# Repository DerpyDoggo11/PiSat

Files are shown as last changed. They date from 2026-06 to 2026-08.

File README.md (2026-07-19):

# PiSat
A GPS Microcontroller for RTK GPS applications

## 3D Preview
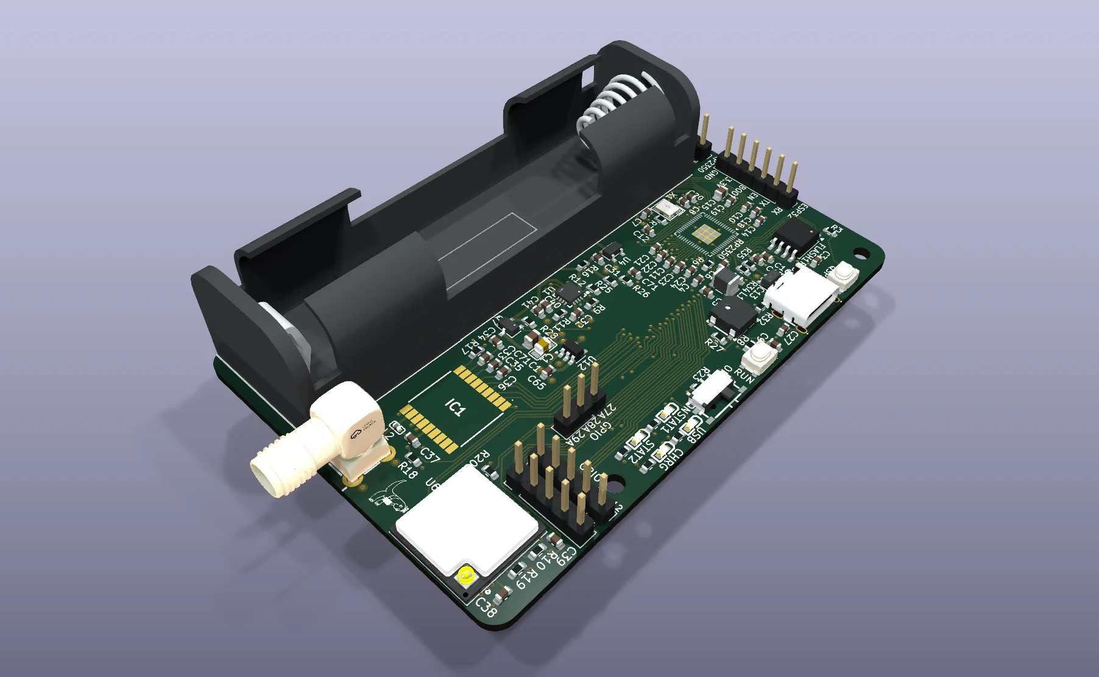
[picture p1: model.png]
3D PCB


## Wiring
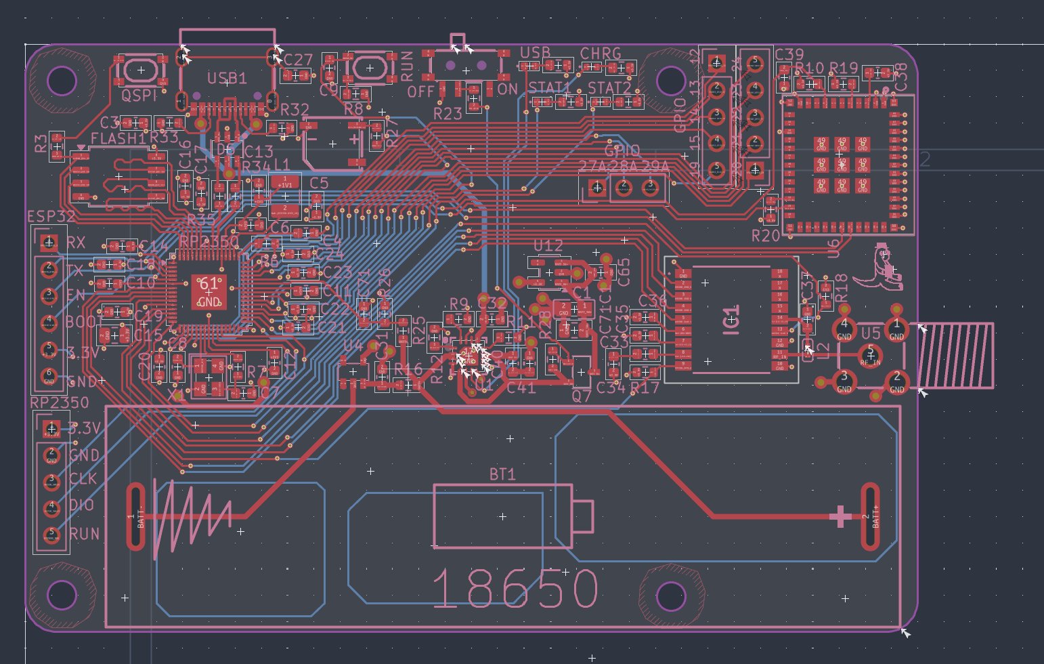
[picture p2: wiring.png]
PCB


## Schematic
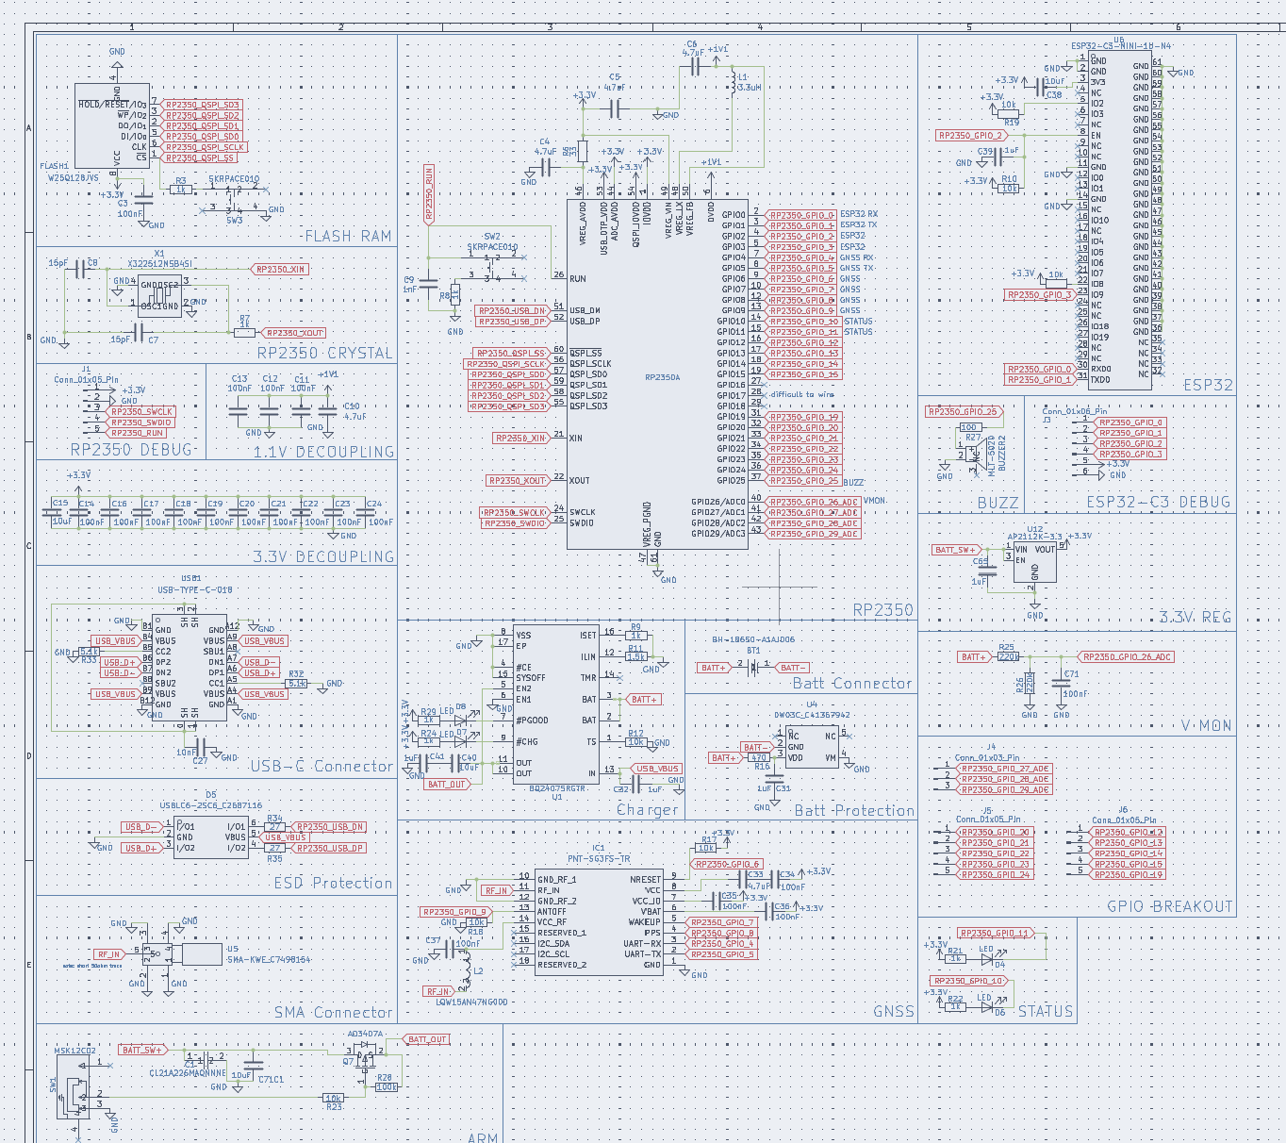
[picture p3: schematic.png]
Schematic


### Download the ./latestProduction folder to begin fabricating through JLCPCB. 

## Introduction
PiSat is a complete microcontroller with an embbedded GPS chip all in the footprint of a Raspbbery Pi. It uses an RP2350 for parallel computing + an esp32 for wifi connectivity. In addition, it uses the PNT-SG3FS-TR GPS chip with an SMA connector to attach an external GPS antenna. It also can run completely on battery power for an estimated 12 hours (based on the suggested battery) at full load.

The main use case for this is in the Real Time Kinematic (RTK) GPS system, which requires two GPS recievers: one at a known location and one at the location being tracked. By calculating the error that both recievers share with other satilletes, this method can track an object down to just a few centimeters. The main drawback to RTK GPS systems is that they usually require expensive mcu for the calculations + external GPS modules which can increase the cost substantially. A fully embbedded approach makes the price much more approachable to hobbists.

Note: this is licensed under the GPL/GNU license which means editing it is fine, just make sure to keep it open source.

## Bill of Materials 

### (Minimum build for RTK GPS system: 2 PiSats)

| Quantity | Components |  Price | Link |
|--- |---|---| -----|
| 2  | 18650 Batteries | ~$20 (with shipping) | [here](https://liionwholesale.com/products/molicel-npe-inr-18650-m35a-10a-3500mah-flat-top-18650-battery-authorized-distributor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)
| 2 | GPS Antenna | $7 (Flexible Antenna) or $10 (Straight Antenna) | [here](https://www.aliexpress.us/item/3256804609969855.html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) or [here](https://www.aliexpress.us/item/3256809038076860.html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)
| 2 | 2.4G Wifi Antenna | $3.55 | [here](https://www.aliexpress.us/item/3256802833801038.html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)
| 2  | PiSat PCBs | ~$100 (with shipping, cost can vary widely however) | Download repo, extract fabrication files from ./latestProduction, and fabricate through JLCPCB (complete instructions for this may come soon)

Total cost: **$130.55**

Cost per unit: **$65.28**

----

## Tools:
- Soldering iron + solder

## Assembly:
1. (If using vertical mount case) Screw into 3 of the mounting holes on the board, only screw into the 1 mounting hole below the battery if completely necessary
2. Solder on the battery connector
3. Screw in the wifi antenna onto the esp32
4. Screw in the GPS antenna onto the SMA connector
5. Insert battery into battery connector and turn on

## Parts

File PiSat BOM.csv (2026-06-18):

Quantity | Component | Price | Link
80 | Brushed DC Motor | $54.88 | https://www.aliexpress.us/item/3256810271706869.html
20 | 1s 450mAh BT2.0 Battery | $61.82 | https://www.aliexpress.us/item/3256810349502140.html?curPageLogUid=6cUgOJiOwfNW
2 | 1s BT2.0 Charger | $36.36 | https://www.aliexpress.us/item/3256811772590472.html?curPageLogUid=pie8lE5eVKgd
20 | BMP581 (hand solder) | $74.76 | https://www.lcsc.com/product-detail/C5362283.html?s_z=s_p_BMP581
20 | LSM6DSRTR (hand solder) | $60.13 | https://www.lcsc.com/product-detail/C784817.html?s_z=s_q_LSM6DSR
20 | BT2.0 Battery Connector | $61 | https://www.aliexpress.us/item/3256809239979303.html?curPageLogUid=TSeGJiqu7rZ1 | Note: select "1S Whoop"
20 | 2.4G Wifi Antenna | $14.08 | https://www.aliexpress.us/item/3256802833801038.html?curPageLogUid=rLnZuf4b98Bi
20 | Custom PCB | $200 | Fab files available on github
Total: | $562.95
Unit Cost: | $25.40

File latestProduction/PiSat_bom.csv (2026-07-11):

Designator | Footprint | Quantity | Value | LCSC Part #
BT1 | BAT-TH_BH-18650-A1AJ006 | 1 | BH-18650-A1AJ006 | C5290175
BUZZER2 | BUZ-SMD_L5.0-W5.5-P4.60 | 1 | MLT-5020 | C94598
C1 | C0805 | 1 | CL21A226MAQNNNE | C45783
C10, C33, C4, C5, C6 | 0603 | 5 | 4.7uF
C11, C12, C13, C14, C16, C17, C18, C19, C20, C21, C22, C23, C24, C3, C34, C35, C36, C37, C71 | 0603 | 19 | 100nF
C15, C71C1 | 0805 | 2 | 10uF
C27 | 0603 | 1 | 10nF
C31, C32, C39, C41, C65 | 0603 | 5 | 1uF
C38, C40 | 0603 | 2 | 10uF
C7, C8 | 0603 | 2 | 15pF
C9 | 0603 | 1 | 1nF
D5 | SOT-23-6_L2.9-W1.6-P0.95-LS2.8-BL | 1 | USBLC6-2SC6_C2687116 | C2687116
FLASH1 | SOIC-8_5.3x5.3mm_P1.27mm | 1 | W25Q128JVS
IC1 | PNTSG3FSTR | 1 | PNT-SG3FS-TR
J1, J5, J6 | PinHeader_1x05_P2.54mm_Vertical | 3 | Conn_01x05_Pin
J3 | PinHeader_1x06_P2.54mm_Vertical | 1 | Conn_01x06_Pin
J4 | PinHeader_1x03_P2.54mm_Vertical | 1 | Conn_01x03_Pin
L1 | 1210 | 1 | 3.3uH
L2 | L0402 | 1 | LQW15AN47NG00D | C22334
LED4, LED5, LED6, LED7 | LED-SMD_L1.6-W0.8-R-RD | 4 | KT-0603R | C2286
Q7 | SOT-23-3_L2.9-W1.6-P1.90-LS2.8-BR | 1 | AO3407A | C15155
R10, R12, R17, R18, R19, R20, R23 | 0603 | 7 | 10k
R11 | 0603 | 1 | 1.5k
R16 | 0603 | 1 | 470
R21, R22, R24, R29, R3, R7, R8, R9 | 0603 | 8 | 1k
R25, R26 | 0603 | 2 | 220k
R27 | 0603 | 1 | 100
R28 | 0603 | 1 | 100k
R32, R33 | 0603 | 2 | 5.1k
R34, R35 | 0603 | 2 | 27
R6 | 0603 | 1 | 33
RP2350 | QFN-60-1EP_7x7mm_P0.4mm_EP3.4x3.4mm | 1 | RP2350A
SW1 | SW-TH_MSK12C02 | 1 | MSK12C02 | C431540
SW2, SW3 | KEY-SMD_4P-L4.2-W3.2-P2.20-LS4.6 | 2 | SKRPACE010 | C139797
U1 | QFN-16_L3.0-W3.0-P0.50-TL-EP1.7 | 1 | BQ24075RGTR | C15464
U12 | SOT-23-5 | 1 | AP2112K-3.3
U4 | SOT-23-5_L2.9-W1.6-P0.95-LS2.9-BL | 1 | DW03C_C41367942 | C41367942
U5 | SMA-TH_SMA-KWE_C7498154 | 1 | SMA-KWE_C7498154 | C7498154
U6 | WIFIM-SMD_61P-L13.2-W12.5-P0.80 | 1 | ESP32-C3-MINI-1U-N4 | C2911374
USB1 | USB-C_SMD-TYPE-C-31-M-12 | 1 | USB-TYPE-C-018 | C2927038
X1 | CRYSTAL-SMD_4P-L3.2-W2.5-BL | 1 | X322512MSB4SI | C9002

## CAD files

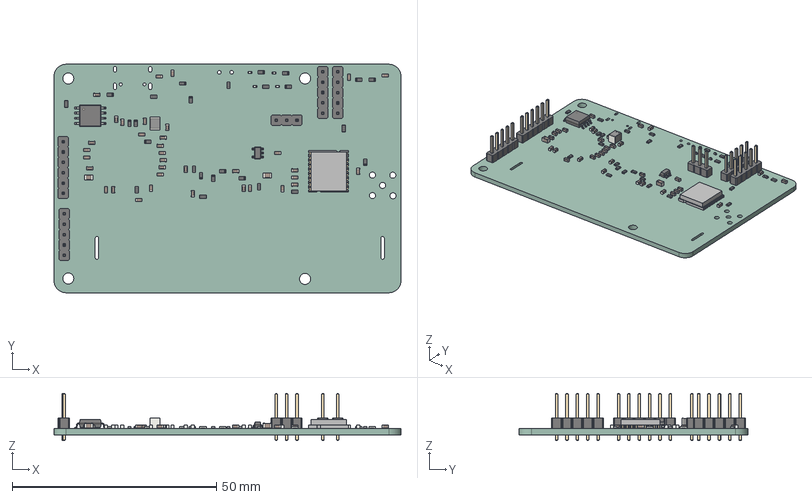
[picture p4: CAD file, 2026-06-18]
latestProduction/PiSat.step
85.0 x 56.0 x 11.5 mm
C_0603_1608Metric x 35
R_0603_1608Metric x 26
PinHeader_1x06_P2.54mm_Vertical
C_0805_2012Metric x 2
LED_0402_1005Metric x 4
L_1210_3225Metric
SOT-23-5
SOIC-8_5.3x5.3mm_P1.27mm
PinHeader_1x03_P2.54mm_Vertical
PinHeader_1x05_P2.54mm_Vertical x 3
PNT-SG3FS-TR
PiSat_PCB

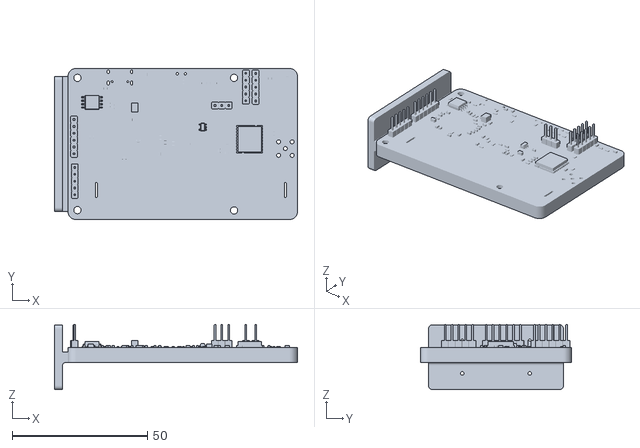
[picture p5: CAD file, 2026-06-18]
PiSat Vertical Mount Case.stl
90.0 x 56.0 x 24.1

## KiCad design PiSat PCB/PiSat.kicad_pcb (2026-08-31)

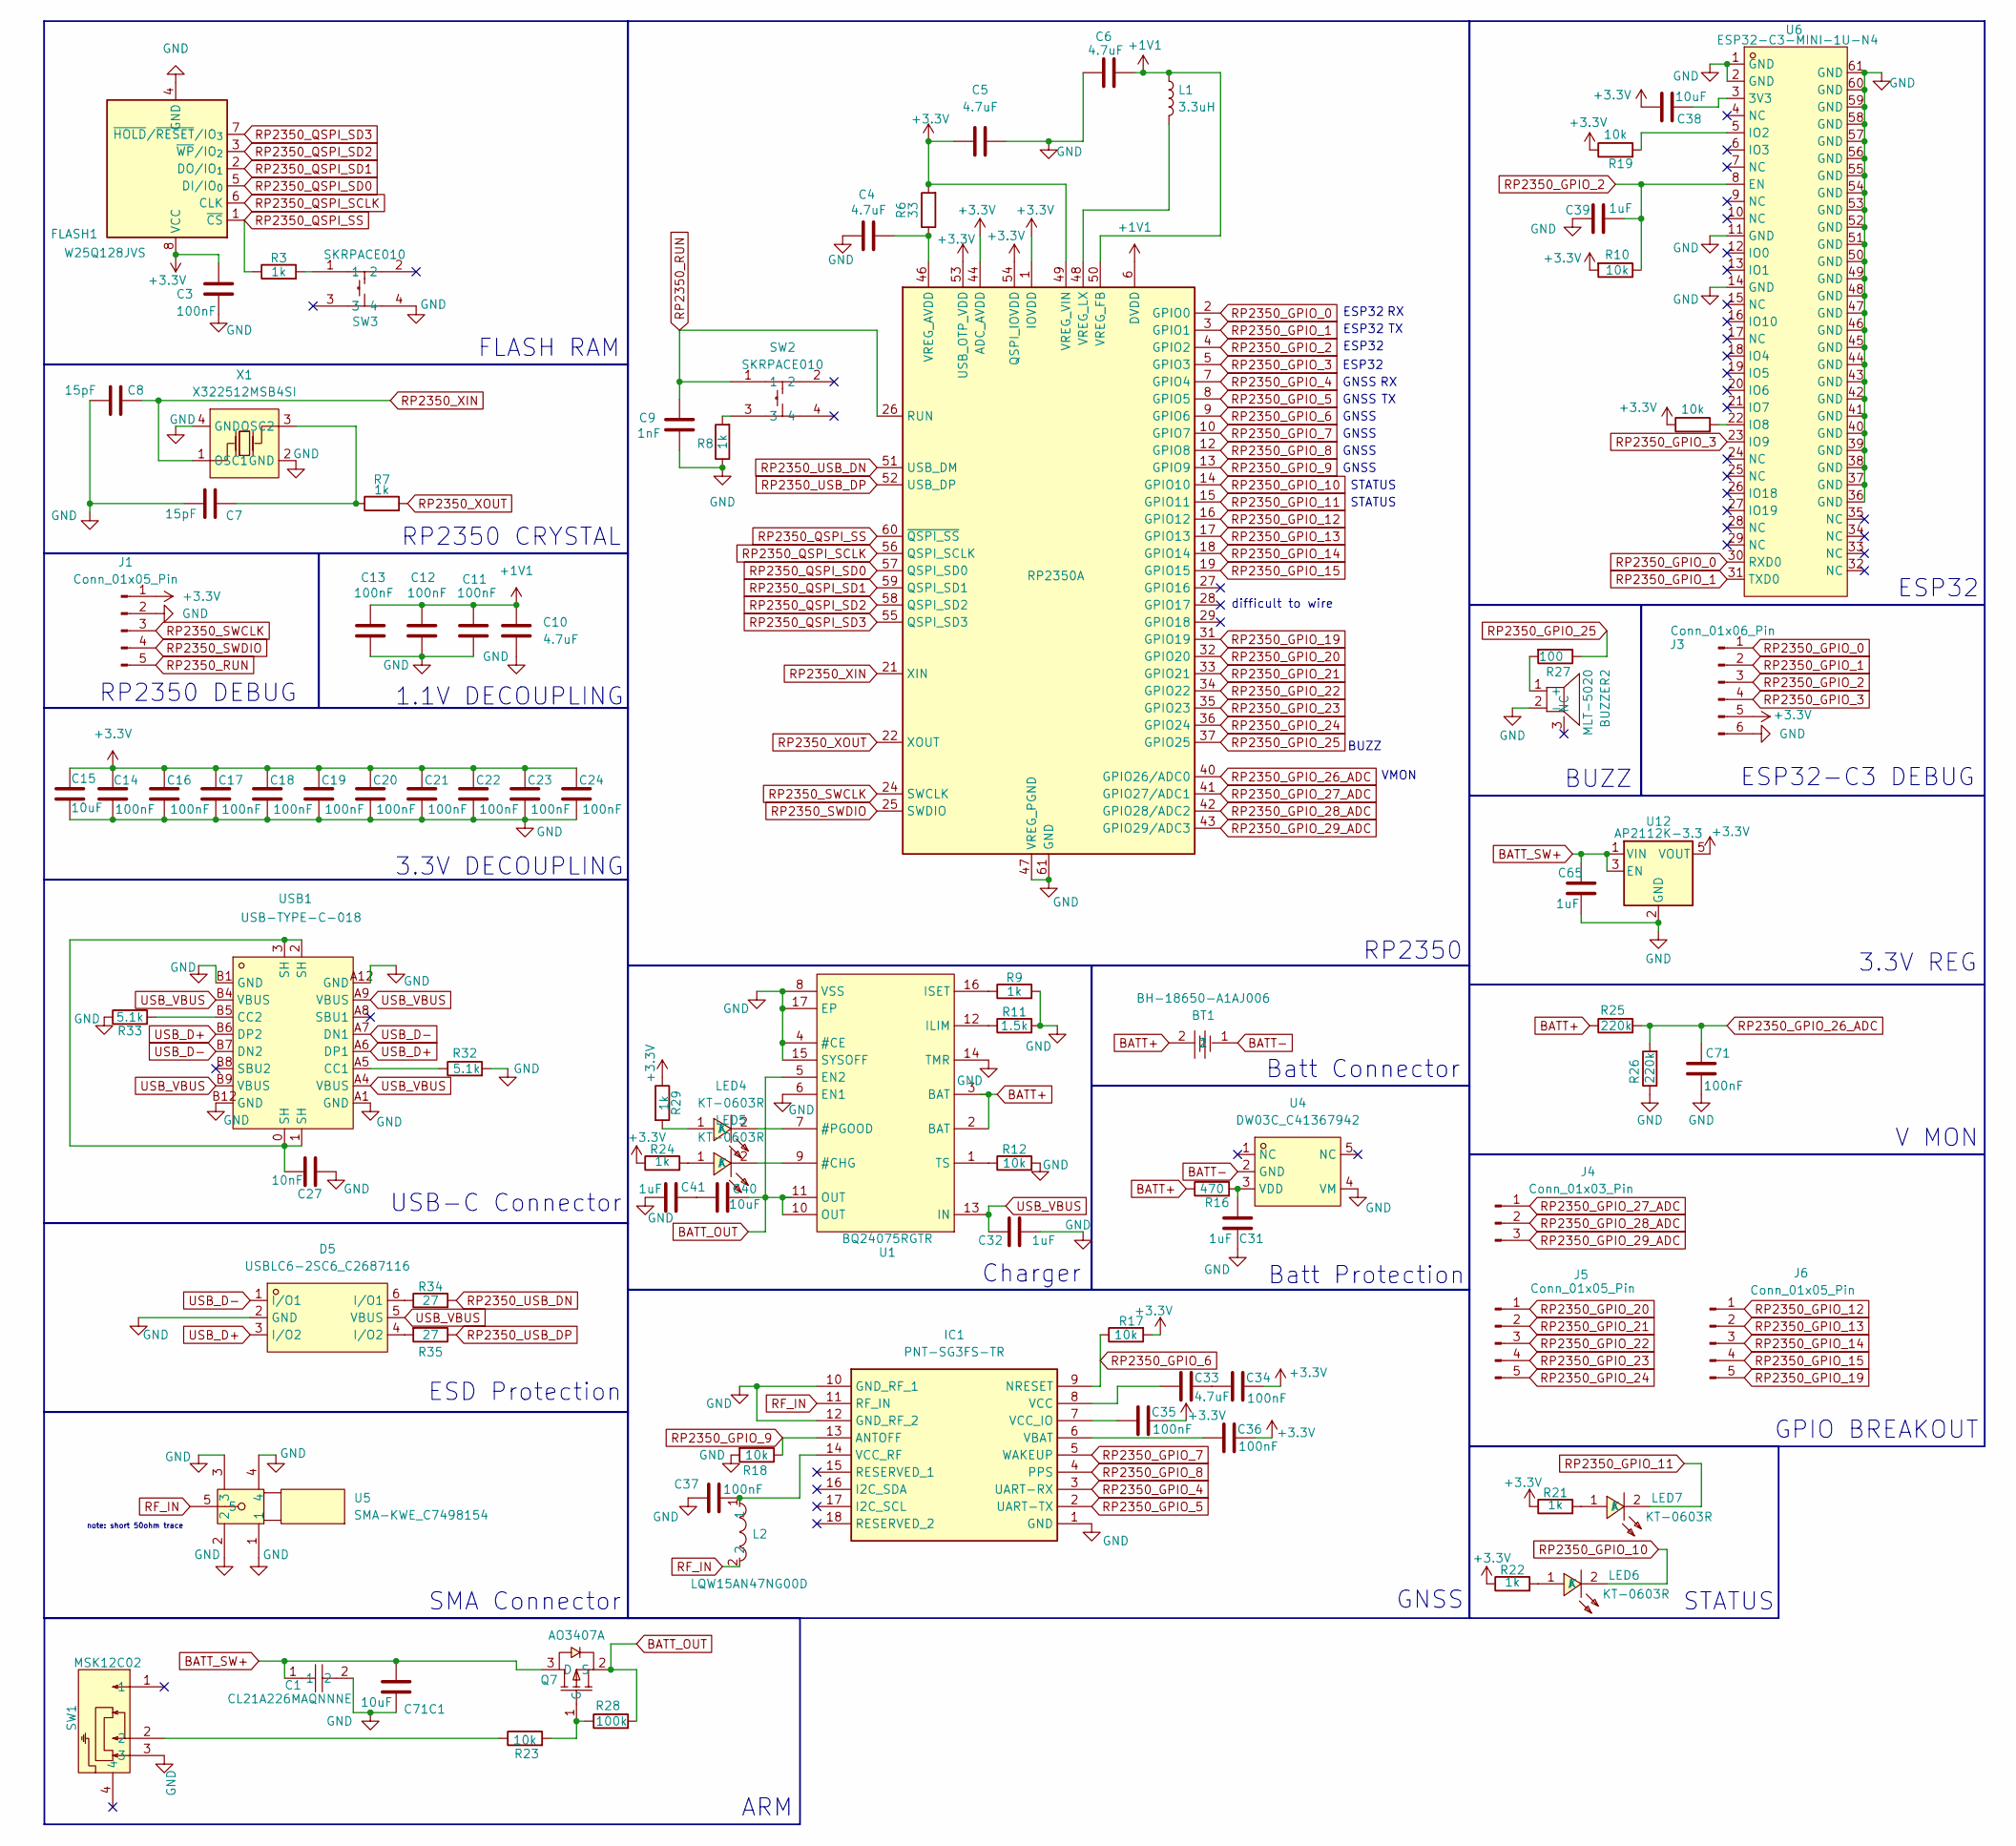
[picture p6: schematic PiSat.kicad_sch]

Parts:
BT1: BH-18650-A1AJ006; BAT-TH_BH-18650-A1AJ006; MPN BH-18650-A1AJ006; LCSC Part C5290175
BUZZER2: MLT-5020; BUZ-SMD_L5.0-W5.5-P4.60; MPN MLT-5020; LCSC Part C94598
C1: CL21A226MAQNNNE; C0805; MPN CL21A226MAQNNNE; LCSC Part C45783
C3, C11, C12, C13, C14, C16, C17, C18, C19, C20, C21, C22, C23, C24, C34, C35, C36, C37, C71: 100nF; C_0603_1608Metric
C4, C5, C6, C10, C33: 4.7uF; C_0603_1608Metric
C7, C8: 15pF; C_0603_1608Metric
C9: 1nF; C_0603_1608Metric
C15, C71C1: 10uF; C_0805_2012Metric
C27: 10nF; C_0603_1608Metric
C31, C32, C39, C41, C65: 1uF; C_0603_1608Metric
C38, C40: 10uF; C_0603_1608Metric
D5: USBLC6-2SC6_C2687116; SOT-23-6_L2.9-W1.6-P0.95-LS2.8-BL; MPN USBLC6-2SC6; LCSC Part C2687116
FLASH1: W25Q128JVS; SOIC-8_5.3x5.3mm_P1.27mm
IC1: PNT-SG3FS-TR; PNTSG3FSTR; Manufacturer_Part_Number PNT-SG3FS-TR
J1, J5, J6: Conn_01x05_Pin; PinHeader_1x05_P2.54mm_Vertical
J3: Conn_01x06_Pin; PinHeader_1x06_P2.54mm_Vertical
J4: Conn_01x03_Pin; PinHeader_1x03_P2.54mm_Vertical
L1: 3.3uH; L_1210_3225Metric
L2: LQW15AN47NG00D; L0402; MPN LQW15AN47NG00D; LCSC Part C22334
LED4, LED5, LED6, LED7: KT-0603R; LED-SMD_L1.6-W0.8-R-RD; MPN KT-0603R; LCSC Part C2286
Q7: AO3407A; SOT-23-3_L2.9-W1.6-P1.90-LS2.8-BR; MPN AO3407A; LCSC Part C15155
R3, R7, R8, R9, R21, R22, R24, R29: 1k; R_0603_1608Metric
R6: 33; R_0603_1608Metric
R10, R12, R17, R18, R19, R20, R23: 10k; R_0603_1608Metric
R11: 1.5k; R_0603_1608Metric
R16: 470; R_0603_1608Metric
R25, R26: 220k; R_0603_1608Metric
R27: 100; R_0603_1608Metric
R28: 100k; R_0603_1608Metric
R32, R33: 5.1k; R_0603_1608Metric
R34, R35: 27; R_0603_1608Metric
RP2350: RP2350A; QFN-60-1EP_7x7mm_P0.4mm_EP3.4x3.4mm
SW1: MSK12C02; SW-TH_MSK12C02; MPN MSK12C02; LCSC Part C431540
SW2, SW3: SKRPACE010; KEY-SMD_4P-L4.2-W3.2-P2.20-LS4.6; MPN SKRPACE010; LCSC Part C139797
U1: BQ24075RGTR; QFN-16_L3.0-W3.0-P0.50-TL-EP1.7; MPN BQ24075RGTR; LCSC Part C15464
U4: DW03C_C41367942; SOT-23-5_L2.9-W1.6-P0.95-LS2.9-BL; MPN DW03C; LCSC Part C41367942
U5: SMA-KWE_C7498154; SMA-TH_SMA-KWE_C7498154; MPN SMA-KWE; LCSC Part C7498154
U6: ESP32-C3-MINI-1U-N4; WIFIM-SMD_61P-L13.2-W12.5-P0.80; MPN ESP32-C3-MINI-1U-N4; LCSC Part C2911374
U12: AP2112K-3.3; SOT-23-5
USB1: USB-TYPE-C-018; USB-C_SMD-TYPE-C-31-M-12; MPN USB-TYPE-C-018; LCSC Part C2927038
X1: X322512MSB4SI; CRYSTAL-SMD_4P-L3.2-W2.5-BL; MPN X322512MSB4SI; LCSC Part C9002

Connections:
+1V1: C6.2, C10.1, C11.1, C12.1, C13.1, L1.1, RP2350.6 (DVDD), RP2350.23 (DVDD), RP2350.39 (DVDD), RP2350.50 (VREG_FB)
+3.3V: C3.1, C5.1, C14.1, C15.1, C16.1, C17.1, C18.1, C19.1, C20.1, C21.1, C22.1, C23.1, C24.1, C34.2, C35.2, C36.2, C38.2, FLASH1.8 (VCC), J1.1, J3.5, R6.2, R10.2, R17.2, R19.1, R20.1, R21.1, R22.1, R24.1, R29.1, RP2350.1 (IOVDD), RP2350.11 (IOVDD), RP2350.20 (IOVDD), RP2350.30 (IOVDD), RP2350.38 (IOVDD), RP2350.44 (ADC_AVDD), RP2350.45 (IOVDD), RP2350.49 (VREG_VIN), RP2350.53 (USB_OTP_VDD), RP2350.54 (QSPI_IOVDD), U12.5 (VOUT)
BATT+: BT1.2, R16.1, R25.1, U1.2 (BAT), U1.3 (BAT)
BATT-: BT1.1, U4.2 (GND)
BATT_OUT: C40.1, Q7.2 (S), R28.2, U1.5 (EN2), U1.10 (OUT), U1.11 (OUT)
BATT_SW+: C1.1, C65.2, C71C1.2, Q7.3 (D), U12.1 (VIN), U12.3 (EN)
GND: BUZZER2.2 (-), C1.2, C3.2, C4.1, C5.2, C6.1, C7.1, C8.1, C9.2, C10.2, C11.2, C12.2, C13.2, C14.2, C15.2, C16.2, C17.2, C18.2, C19.2, C20.2, C21.2, C22.2, C23.2, C24.2, C27.1, C31.2, C32.1, C37.1, C39.1, C41.1, C65.1, C71.1, C71C1.1, D5.2 (GND), FLASH1.4 (GND), IC1.1 (GND), IC1.10 (GND_RF_1), IC1.12 (GND_RF_2), J1.2, J3.6, R8.1, R9.2, R11.2, R12.2, R18.2, R26.1, R32.2, R33.1, RP2350.47 (VREG_PGND), RP2350.61 (GND), SW1.3, SW3.4, U1.4 (#CE), U1.6 (EN1), U1.8 (VSS), U1.14 (TMR), U1.15 (SYSOFF), U1.17 (EP), U4.4 (VM), U5.1, U5.2, U5.3, U5.4, U6.1 (GND), U6.2 (GND), U6.11 (GND), U6.14 (GND), U6.36 (GND), U6.37 (GND), U6.38 (GND), U6.39 (GND), U6.40 (GND), U6.41 (GND), U6.42 (GND), U6.43 (GND), U6.44 (GND), U6.45 (GND), U6.46 (GND), U6.47 (GND), U6.48 (GND), U6.49 (GND), U6.50 (GND), U6.51 (GND), U6.52 (GND), U6.53 (GND), U6.54 (GND), U6.55 (GND), U6.56 (GND), U6.57 (GND), U6.58 (GND), U6.59 (GND), U6.60 (GND), U6.61 (GND), U12.2 (GND), USB1.A1 (GND), USB1.A12 (GND), USB1.B1 (GND), USB1.B12 (GND), X1.2 (GND), X1.4 (GND)
unnamed: BUZZER2.1 (+), R27.2
unnamed: C27.2, USB1.0 (SH), USB1.1 (SH), USB1.2 (SH), USB1.3 (SH)
unnamed: C33.2, C34.1
unnamed: C40.2, C41.2
unnamed: D5.6 (I/O1), R34.1
unnamed: D5.4 (I/O2), R35.2
unnamed: C36.1, IC1.6 (VBAT)
unnamed: C33.1, IC1.8 (VCC)
unnamed: C35.1, IC1.7 (VCC_IO)
unnamed: C37.2, IC1.14 (VCC_RF), L2.1
unnamed: LED4.1 (A), R29.2
unnamed: LED4.2 (K), U1.7 (#PGOOD)
unnamed: LED5.1 (A), R24.2
unnamed: LED5.2 (K), U1.9 (#CHG)
unnamed: LED6.1 (A), R22.2
unnamed: LED7.1 (A), R21.2
unnamed: Q7.1 (G), R23.2, R28.1
unnamed: R3.2, SW3.1
unnamed: R8.2, SW2.3
unnamed: R23.1, SW1.2
unnamed: C4.2, R6.1, RP2350.46 (VREG_AVDD)
unnamed: L1.2, RP2350.48 (VREG_LX)
unnamed: R11.1, U1.12 (ILIM)
unnamed: R9.1, U1.16 (ISET)
unnamed: R12.1, U1.1 (TS)
unnamed: C31.1, R16.2, U4.3 (VDD)
unnamed: C38.1, U6.3 (3V3)
unnamed: R19.2, U6.5 (IO2)
unnamed: R20.2, U6.22 (IO8)
unnamed: R32.1, USB1.A5 (CC1)
unnamed: R33.2, USB1.B5 (CC2)
unnamed: C7.2, R7.1, X1.3 (OSC2)
RF_IN: IC1.11 (RF_IN), L2.2, U5.5
RP2350_GPIO_0: J3.1, RP2350.2 (GPIO0), U6.30 (RXD0)
RP2350_GPIO_1: J3.2, RP2350.3 (GPIO1), U6.31 (TXD0)
RP2350_GPIO_2: C39.2, J3.3, R10.1, RP2350.4 (GPIO2), U6.8 (EN)
RP2350_GPIO_3: J3.4, RP2350.5 (GPIO3), U6.23 (IO9)
RP2350_GPIO_4: IC1.3 (UART-RX), RP2350.7 (GPIO4)
RP2350_GPIO_5: IC1.2 (UART-TX), RP2350.8 (GPIO5)
RP2350_GPIO_6: IC1.9 (NRESET), R17.1, RP2350.9 (GPIO6)
RP2350_GPIO_7: IC1.5 (WAKEUP), RP2350.10 (GPIO7)
RP2350_GPIO_8: IC1.4 (PPS), RP2350.12 (GPIO8)
RP2350_GPIO_9: IC1.13 (ANTOFF), R18.1, RP2350.13 (GPIO9)
RP2350_GPIO_10: LED6.2 (K), RP2350.14 (GPIO10)
RP2350_GPIO_11: LED7.2 (K), RP2350.15 (GPIO11)
RP2350_GPIO_12: J6.1, RP2350.16 (GPIO12)
RP2350_GPIO_13: J6.2, RP2350.17 (GPIO13)
RP2350_GPIO_14: J6.3, RP2350.18 (GPIO14)
RP2350_GPIO_15: J6.4, RP2350.19 (GPIO15)
RP2350_GPIO_19: J6.5, RP2350.31 (GPIO19)
RP2350_GPIO_20: J5.1, RP2350.32 (GPIO20)
RP2350_GPIO_21: J5.2, RP2350.33 (GPIO21)
RP2350_GPIO_22: J5.3, RP2350.34 (GPIO22)
RP2350_GPIO_23: J5.4, RP2350.35 (GPIO23)
RP2350_GPIO_24: J5.5, RP2350.36 (GPIO24)
RP2350_GPIO_25: R27.1, RP2350.37 (GPIO25)
RP2350_GPIO_26_ADC: C71.2, R25.2, R26.2, RP2350.40 (GPIO26/ADC0)
RP2350_GPIO_27_ADC: J4.1, RP2350.41 (GPIO27/ADC1)
RP2350_GPIO_28_ADC: J4.2, RP2350.42 (GPIO28/ADC2)
RP2350_GPIO_29_ADC: J4.3, RP2350.43 (GPIO29/ADC3)
RP2350_QSPI_SCLK: FLASH1.6 (CLK), RP2350.56 (QSPI_SCLK)
RP2350_QSPI_SD0: FLASH1.5 (DI/IO_{0}), RP2350.57 (QSPI_SD0)
RP2350_QSPI_SD1: FLASH1.2 (DO/IO_{1}), RP2350.59 (QSPI_SD1)
RP2350_QSPI_SD2: FLASH1.3 (~WP/IO_{2}), RP2350.58 (QSPI_SD2)
RP2350_QSPI_SD3: FLASH1.7 (~HOLD/~RESET/IO_{3}), RP2350.55 (QSPI_SD3)
RP2350_QSPI_SS: FLASH1.1 (~CS), R3.1, RP2350.60 (~QSPI_SS)
RP2350_RUN: C9.1, J1.5, RP2350.26 (RUN), SW2.1
RP2350_SWCLK: J1.3, RP2350.24 (SWCLK)
RP2350_SWDIO: J1.4, RP2350.25 (SWDIO)
RP2350_USB_DN: R34.2, RP2350.51 (USB_DM)
RP2350_USB_DP: R35.1, RP2350.52 (USB_DP)
RP2350_XIN: C8.2, RP2350.21 (XIN), X1.1 (OSC1)
RP2350_XOUT: R7.2, RP2350.22 (XOUT)
USB_D+: D5.3 (I/O2), USB1.A6 (DP1), USB1.B6 (DP2)
USB_D-: D5.1 (I/O1), USB1.A7 (DN1), USB1.B7 (DN2)
USB_VBUS: C32.2, D5.5 (VBUS), U1.13 (IN), USB1.A4 (VBUS), USB1.A9 (VBUS), USB1.B4 (VBUS), USB1.B9 (VBUS)

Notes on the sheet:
GNSS
FLASH RAM
V MON
note: short 50ohm trace
ESP32-C3 DEBUG
Batt Protection
STATUS
RP2350 CRYSTAL
ESP32
ARM
BUZZ
ESD Protection
difficult to wire
SMA Connector
GPIO BREAKOUT
Charger
VMON
RP2350
3.3V DECOUPLING
3.3V REG
USB-C Connector
RP2350 DEBUG
Batt Connector
1.1V DECOUPLING

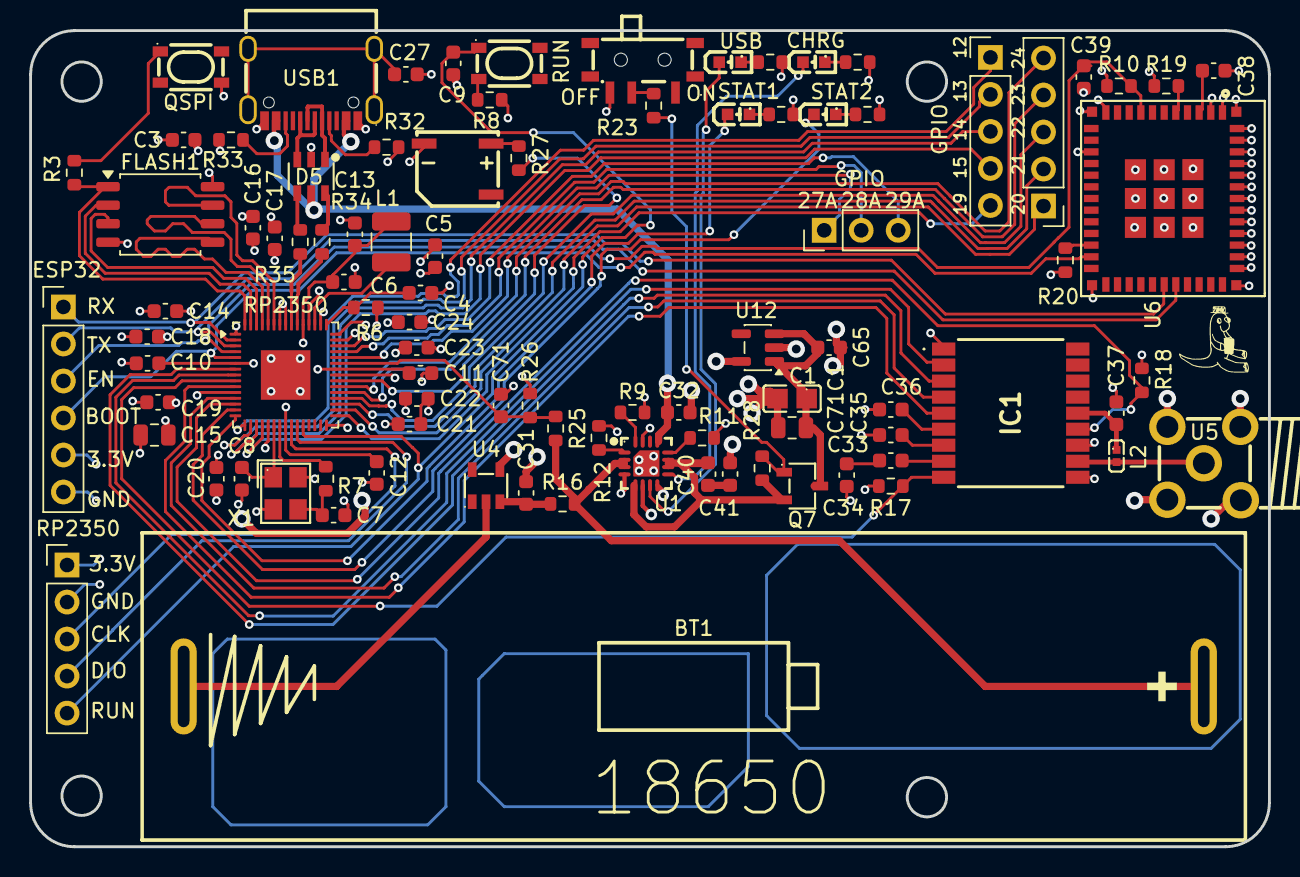
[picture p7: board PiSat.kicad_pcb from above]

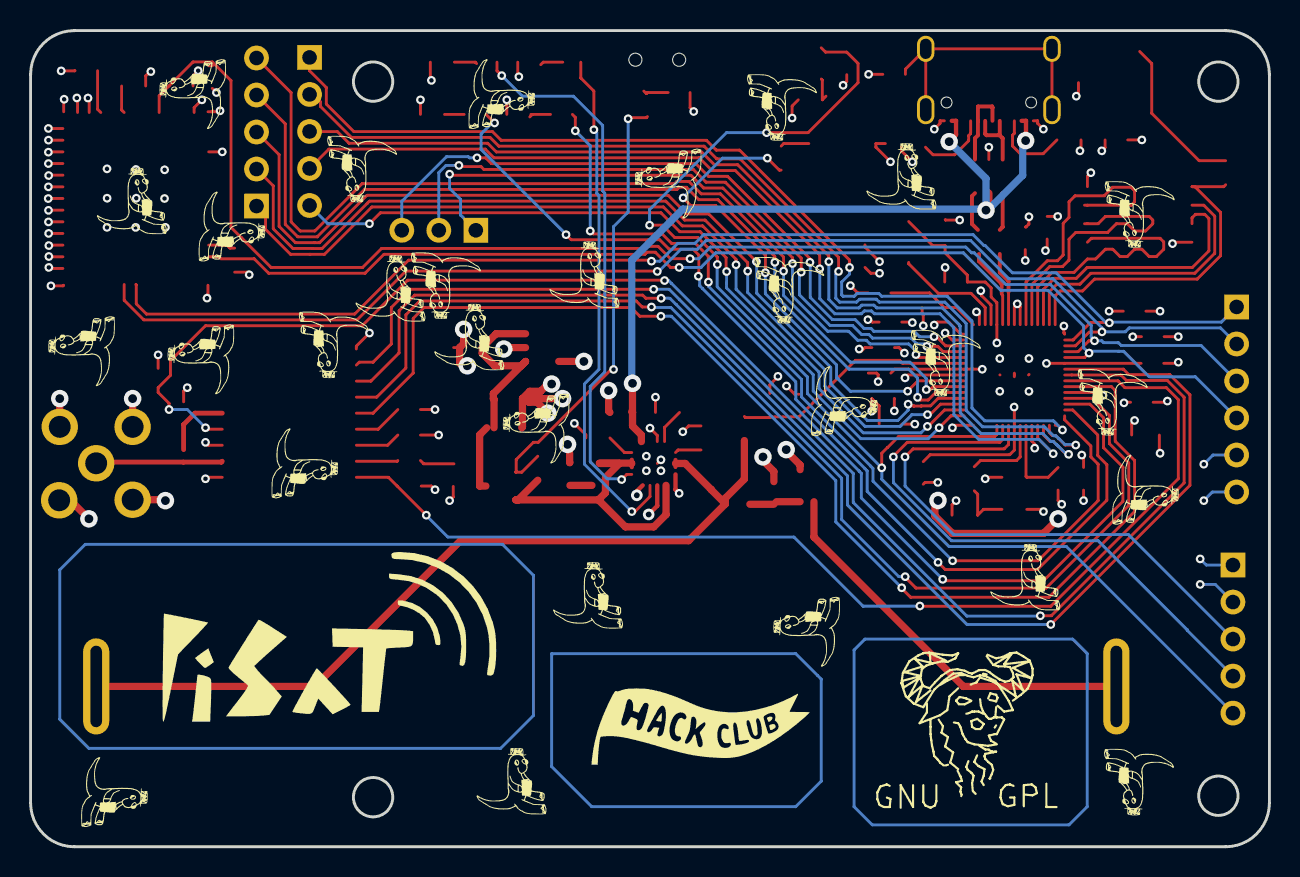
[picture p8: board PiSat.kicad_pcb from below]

Board: 4 copper layers, 85.0 x 56.0 mm, 94 parts (2 on the bottom side), 83 nets.

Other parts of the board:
GNU: Symbol_GNU-Logo_SilkscreenTop
hackclub: LOGO; hackclub

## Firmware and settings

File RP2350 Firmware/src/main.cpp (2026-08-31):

#include <Arduino.h>
#include "pins.h"
#include "gnss.h"
#include "esc.h"
#include "hmi.h"
#include "esplink.h"

#if defined(ESP_PASSTHROUGH_ONLY)

void setup() {
    Serial.begin(115200);
    Hmi::begin();
    Esc::begin();
    Esc::disarm();
    EspLink::begin();
    EspLink::passthrough();
}
void loop() {}

#else

static volatile float g_throttle[4] = {0, 0, 0, 0};
static volatile bool  g_armed = false;
static float g_vbat  = 0.0f;

// CORE 0 
void setup() {
    Serial.begin(115200);

    Hmi::begin();
    Power::begin();
    EspLink::begin();
    Gnss::begin();

    for (uint8_t i = 0; i < 5; i++) pinMode(PIN_J6[i], INPUT);

    uint32_t t0 = millis();
    while (!Serial && millis() - t0 < 2000) { }

    Serial.println("=== GNSS / BLDC board (RP2350A) ===");
    Serial.printf("VBAT: %.2f V\n", Power::batteryVolts());
    Serial.println("Type 'help' for commands, 'esp_bridge' to flash the ESP32.");

    Hmi::beep(60);
}

static void handleCommand(char* cmd) {
    if (!strcmp(cmd, "help")) {
        Serial.println("arm | disarm | t <0-3> <0.0-1.0> | tall <0.0-1.0> |");
        Serial.println("gps | aux | stat | gnss_reset | nmea | ant on|off |");
        Serial.println("esp_reset | esp_boot | esp_bridge");
    }
    else if (!strcmp(cmd, "arm")) {
        if (g_vbat < Power::VBAT_CRITICAL) {
            Serial.println("refused: battery too low");
            return;
        }
        Serial.println("arming ESCs (2 s of min throttle)...");
        Esc::arm();
        g_armed = true;
        Hmi::beep(150);
        Serial.println("ARMED");
    }
    else if (!strcmp(cmd, "disarm")) {
        g_armed = false;
        for (uint8_t i = 0; i < 4; i++) g_throttle[i] = 0.0f;
        Esc::disarm();
        Serial.println("disarmed");
    }
    else if (!strncmp(cmd, "tall ", 5)) {
        float v = atof(cmd + 5);
        for (uint8_t i = 0; i < 4; i++) g_throttle[i] = constrain(v, 0.f, 1.f);
        Serial.printf("all = %.2f\n", v);
    }
    else if (!strncmp(cmd, "t ", 2)) {
        int idx; float v;
        if (sscanf(cmd + 2, "%d %f", &idx, &v) == 2 && idx >= 0 && idx < 4) {
            g_throttle[idx] = constrain(v, 0.0f, 1.0f);
            Serial.printf("esc %d = %.2f\n", idx, g_throttle[idx]);
        }
    }
    else if (!strcmp(cmd, "gps")) {
        const GnssFix& f = Gnss::fix();
        if (Gnss::hasFix()) {
            Serial.printf("fix q%u  %.6f, %.6f  alt %.1f m  %.1f m/s  " "hdg %.0f  sats %u  hdop %.1f  %02u:%02u:%02uZ\n", f.fixQuality, f.latitude, f.longitude, f.altitude_m, f.speed_mps, f.course_deg, f.satellites, f.hdop, f.hour, f.minute, f.second);
        } else {
            Serial.printf("no fix (sats %u, pps %lu)\n", f.satellites, (unsigned long)Gnss::ppsCount());
        }
    }
    else if (!strcmp(cmd, "aux")) {
        Serial.printf("J4: A1 %.3fV  A2 %.3fV  A3 %.3fV\n", Power::readAux(0), Power::readAux(1), Power::readAux(2));
    }
    else if (!strcmp(cmd, "stat")) {
        Serial.printf("vbat %.2f V  usb %d  armed %d  pps %lu  fix %d\n", g_vbat, (int)Power::usbPresent(), (int)g_armed, (unsigned long)Gnss::ppsCount(), (int)Gnss::hasFix());
    }
    else if (!strcmp(cmd, "gnss_reset")) { Gnss::reset(); Serial.println("gnss reset"); }
    else if (!strcmp(cmd, "nmea")) {
        bool on = !Gnss::rawDebug();
        Gnss::setRawDebug(on);
        Serial.printf("raw NMEA echo %s\n", on ? "ON (type 'nmea' again to stop)" : "OFF");
    }
    else if (!strcmp(cmd, "ant on")) { Gnss::antennaPower(true);  Serial.println("ant on"); }
    else if (!strcmp(cmd, "ant off")) { Gnss::antennaPower(false); Serial.println("ant off"); }
    else if (!strcmp(cmd, "esp_reset")) { EspLink::reset(); Serial.println("esp reset"); }
    else if (!strcmp(cmd, "esp_boot")) { EspLink::enterBootloader(); Serial.println("esp bootloader"); }
    else if (!strcmp(cmd, "esp_bridge")) {
        g_armed = false;
        Esc::disarm();
        Serial.println("entering programmer mode - reset the RP2350 to exit");
        Serial.flush();
        EspLink::passthrough();
    }
}

void loop() {
    Gnss::poll();

    static char line[64];
    static uint8_t n = 0;
    while (Serial.available()) {
        char c = (char)Serial.read();
        if (c == '\n' || c == '\r') {
            if (n) { line[n] = 0; handleCommand(line); n = 0; }
        } else if (n < sizeof(line) - 1) {
            line[n++] = c;
        }
    }

    while (Serial1.available()) Serial.write((char)Serial1.read());

    static uint32_t tLast = 0;
    if (millis() - tLast >= 100) {
        tLast = millis();
        g_vbat = Power::batteryVolts();

        if (Gnss::hasFix()) Hmi::ledA(true);
        else Hmi::blink(PIN_LED_A, 500);

        if (g_vbat < Power::VBAT_WARN) Hmi::blink(PIN_LED_B, 125);
        else Hmi::ledB(g_armed);

        if (g_armed && g_vbat < Power::VBAT_CRITICAL) {
            g_armed = false;
            for (uint8_t i = 0; i < 4; i++) g_throttle[i] = 0.0f;
            Esc::disarm();
            Hmi::beep(400);
            Serial.println("!! low voltage cutoff - disarmed");
        }
    }
}

// CORE 1

void setup1() {
    Esc::begin();
}

void loop1() {
    static uint32_t next = 0;
    uint32_t now = micros();
    if ((int32_t)(now - next) < 0) return;
    next = now + 10000;

    if (!g_armed) { Esc::disarm(); return; }

    for (uint8_t i = 0; i < 4; i++) Esc::setThrottle(i, g_throttle[i]);
}

#endif

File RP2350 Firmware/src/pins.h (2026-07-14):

#pragma once
#include <Arduino.h>

// ESP32
static constexpr uint8_t PIN_ESP_TX = 0;
static constexpr uint8_t PIN_ESP_RX = 1;
static constexpr uint8_t PIN_ESP_EN = 2;
static constexpr uint8_t PIN_ESP_BOOT = 3;

// GNSS
static constexpr uint8_t PIN_GNSS_TX = 4; 
static constexpr uint8_t PIN_GNSS_RX = 5; 
static constexpr uint8_t PIN_GNSS_NRESET = 6;
static constexpr uint8_t PIN_GNSS_WAKEUP = 7;
static constexpr uint8_t PIN_GNSS_PPS = 8;
static constexpr uint8_t PIN_GNSS_ANTOFF = 9;

static constexpr uint32_t GNSS_BAUD = 9600; 

// Status
static constexpr uint8_t PIN_LED_A = 10;
static constexpr uint8_t PIN_LED_B = 11; 

#define STATUS_LED_ACTIVE_LOW 1

static constexpr uint8_t PIN_BUZZER = 25;

// Breakout 
static constexpr uint8_t PIN_ESC[4] = {20, 21, 22, 23};
static constexpr uint8_t PIN_J5_SPARE = 24;

static constexpr uint8_t PIN_J6[5] = {12, 13, 14, 15, 19};

static constexpr uint8_t PIN_J4_ADC[3] = {27, 28, 29};

// Power 
static constexpr uint8_t PIN_VBAT_ADC = 26; 
static constexpr float VBAT_DIVIDER = 2.0f;
static constexpr float ADC_VREF = 3.3f;

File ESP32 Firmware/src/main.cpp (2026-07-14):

#include <Arduino.h>
#include <SPI.h>
#include "pins.h"

static SPIClass dwSpi(FSPI);

static void dwHardReset() {
  pinMode(PIN_DW_RST, OUTPUT);
  digitalWrite(PIN_DW_RST, LOW);
  delay(2);
  pinMode(PIN_DW_RST, INPUT);
  delay(5);
}

static bool dwBegin() {
  pinMode(PIN_DW_CS, OUTPUT);
  digitalWrite(PIN_DW_CS, HIGH);
  pinMode(PIN_DW_WAKEUP, OUTPUT);
  digitalWrite(PIN_DW_WAKEUP, LOW);
  pinMode(PIN_DW_IRQ, INPUT);

  dwSpi.begin(PIN_DW_CLK, PIN_DW_MISO, PIN_DW_MOSI, PIN_DW_CS);
  dwHardReset();

  uint8_t hdr[2] = {0x00, 0x00};
  uint8_t id[4]  = {0};
  dwSpi.beginTransaction(SPISettings(2000000, MSBFIRST, SPI_MODE0));
  digitalWrite(PIN_DW_CS, LOW);
  dwSpi.transfer(hdr, 2);
  dwSpi.transfer(id, 4);
  digitalWrite(PIN_DW_CS, HIGH);
  dwSpi.endTransaction();

  uint32_t devid = (uint32_t)id[3] << 24 | (uint32_t)id[2] << 16 | (uint32_t)id[1] << 8 | id[0];
  Serial0.printf("S,UWB devid=0x%08lX\n", (unsigned long)devid);
  return devid != 0x00000000 && devid != 0xFFFFFFFF;
}

void setup() {
  Serial0.begin(LINK_BAUD, SERIAL_8N1, PIN_LINK_RX, PIN_LINK_TX);
  delay(50);
  Serial0.println("S,esp32-c3 boot");

  analogReadResolution(12);

}


void loop() {--
    static char line[64];
    static uint8_t n = 0;
 
    static uint32_t t = 0;
    if (millis() - t >= 100) {
        t = millis();
 
        float x = 0, y = 0, z = 0;
        int quality = 0;
 
        Serial0.printf("P,%.3f,%.3f,%.3f,%d\n", x, y, z, quality);
    }
 
    static uint32_t tv = 0;
    if (millis() - tv >= 2000) {
        tv = millis();
        int raw = analogRead(PIN_VMON_ADC);
        Serial0.printf("S,vmon=%d\n", raw);
    }
}

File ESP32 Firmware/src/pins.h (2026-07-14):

#pragma once
#include <cstdint>

static constexpr int PIN_VMON_ADC = 0;

static constexpr int PIN_DW_WAKEUP = 1;
static constexpr int PIN_DW_IRQ    = 3;
static constexpr int PIN_DW_MISO   = 4;
static constexpr int PIN_DW_MOSI   = 5;
static constexpr int PIN_DW_CLK    = 6;
static constexpr int PIN_DW_CS     = 7;
static constexpr int PIN_DW_RST    = 10;

static constexpr int PIN_LINK_RX = 20;
static constexpr int PIN_LINK_TX = 21;
static constexpr uint32_t LINK_BAUD = 115200;

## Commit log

2026-06-18 fixed flash ram wiring + added readme
    [PiSat Vertical Mount Case.stl, PiSat.kicad_pcb, PiSat.step]
2026-09-09 before esp32 wipe
